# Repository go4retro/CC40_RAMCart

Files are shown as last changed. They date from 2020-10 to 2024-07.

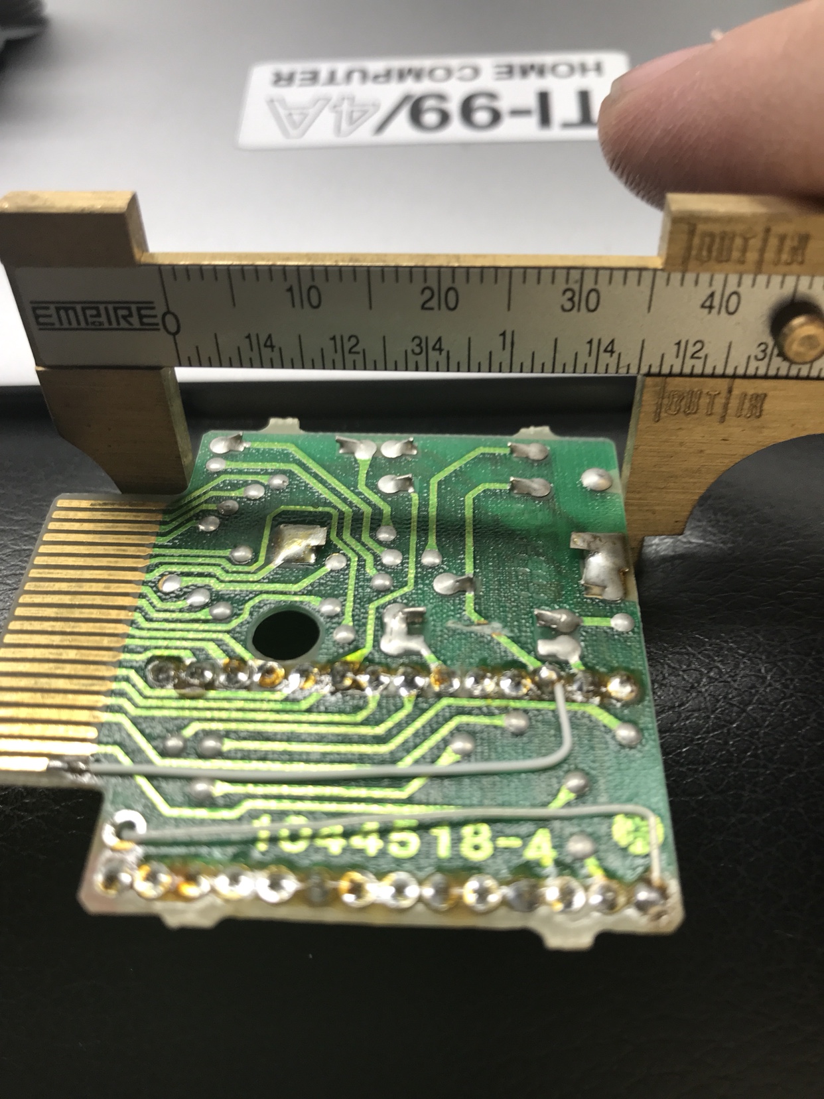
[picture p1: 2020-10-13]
ref/c301821a8f4df3ecedaf89124f83f544.jpg

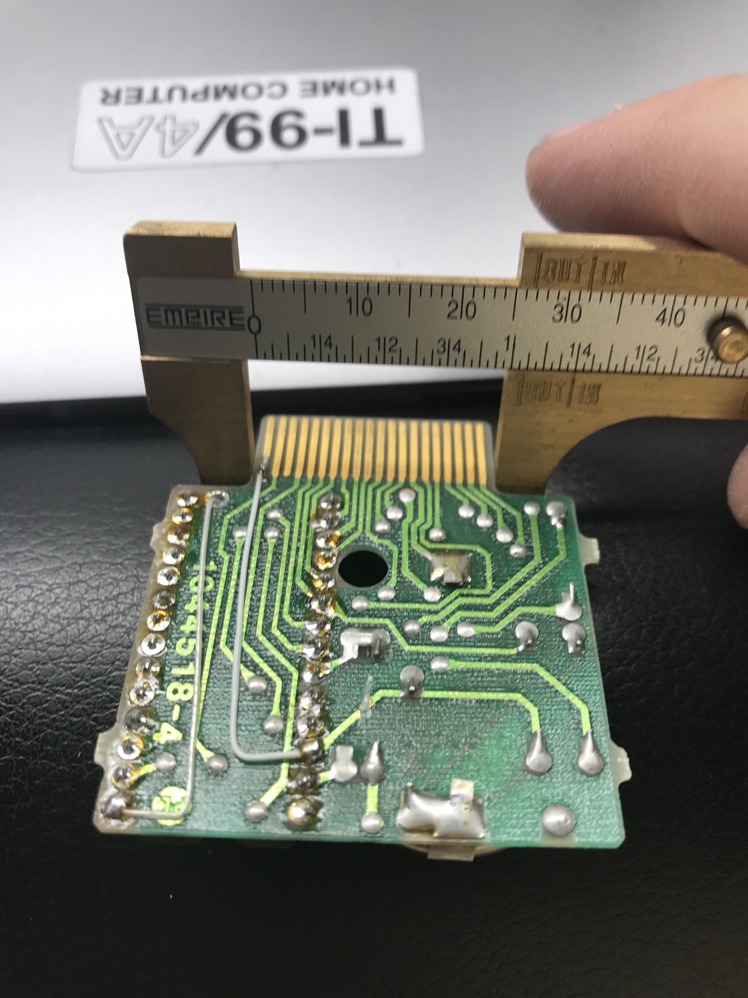
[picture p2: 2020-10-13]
ref/0288a4b47281a45af204f250dd83d3cb.jpg

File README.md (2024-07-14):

## Introduction

Join the growing ranks of Texas Instruments Compact Computer 40 owners who now have increased access to RAM storage on their machine. This CC-40 RAM cartridge replicates the functionality of the original 32kB RAM cartridge option and also expands it 4, 8 or 16 times to  128KB, 256KB, or 512KB.  Easy access DIP switches on the rear of the unit allow one to select which 32kB bank is in use, and all banks are preserved with the optional 3V battery.

Discussion around the design can be reviewed on the AtariAge forum [discussion](https://atariage.com/forums/topic/255728-the-compact-computer-40-cc40/). 

### Main features

- Mimics original PCB location and size
- 4, 8, or 16X capacity
- Easy access to change accessed bank

### Technical Features

- Low power SRAM IC sips battery power when off
- Optional use of P25.2 and P25.3 signals on cartridge port to select RAM bank

## Purchase

This PCB can be purchased in the [RETRO Innovations Online Store](http://store.go4retro.com/ti-compact-computer-40-prototype-boards/).

## License

Copyright (C) 2018  RETRO Innovations

These files are free designs; you can redistribute them and/or modify
them under the terms of the Creative Commons Attribution-ShareAlike 
4.0 International License.

You should have received a copy of the license along with this
work. If not, see <http://creativecommons.org/licenses/by-sa/4.0/>.

These files are distributed in the hope that they will be useful,
but WITHOUT ANY WARRANTY; without even the implied warranty of
MERCHANTABILITY or FITNESS FOR A PARTICULAR PURPOSE.  See the
license for more details.

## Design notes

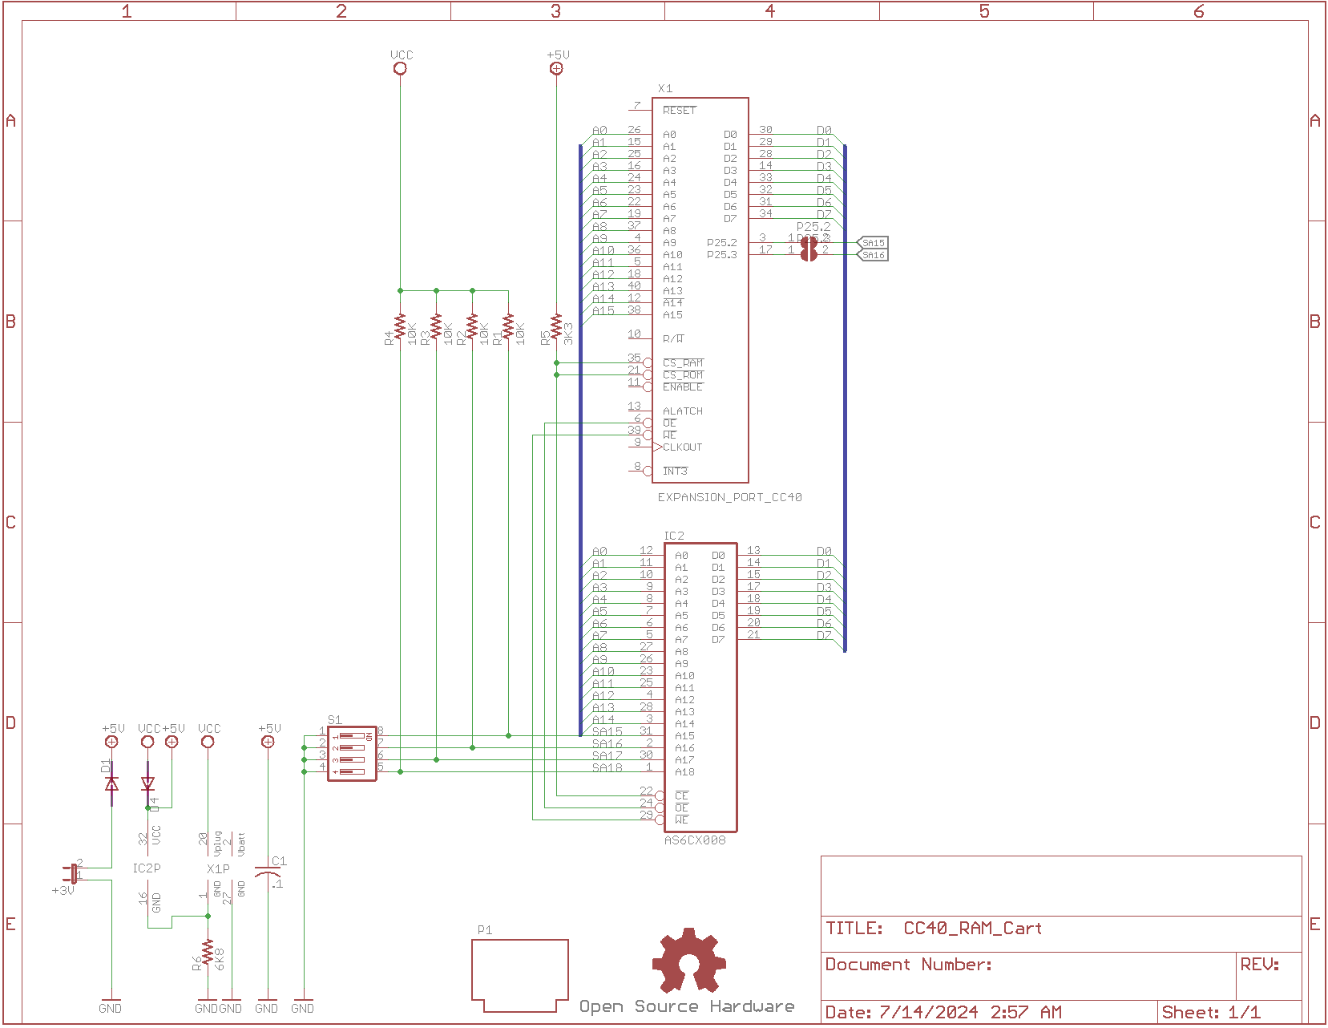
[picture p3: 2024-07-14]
pcb/cc40 RAM Cart Schematic.png

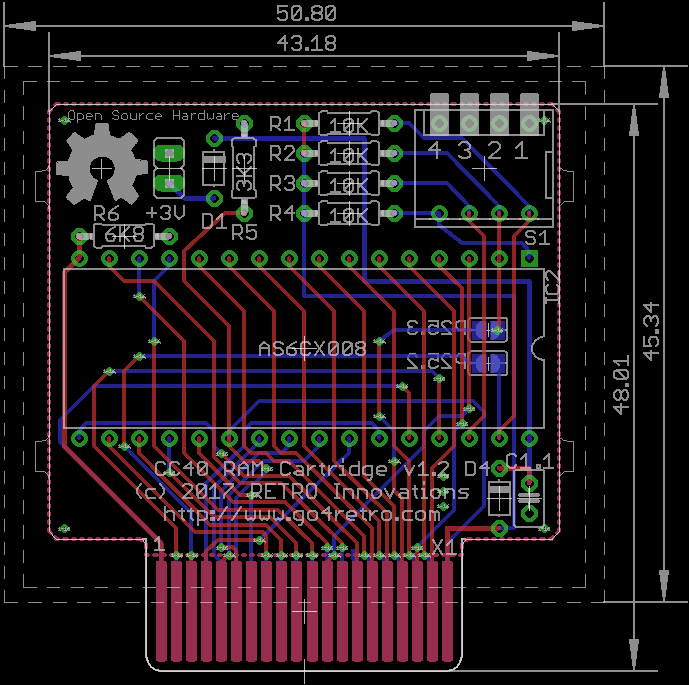
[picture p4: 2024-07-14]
pcb/cc40 RAM Cart PCB.png

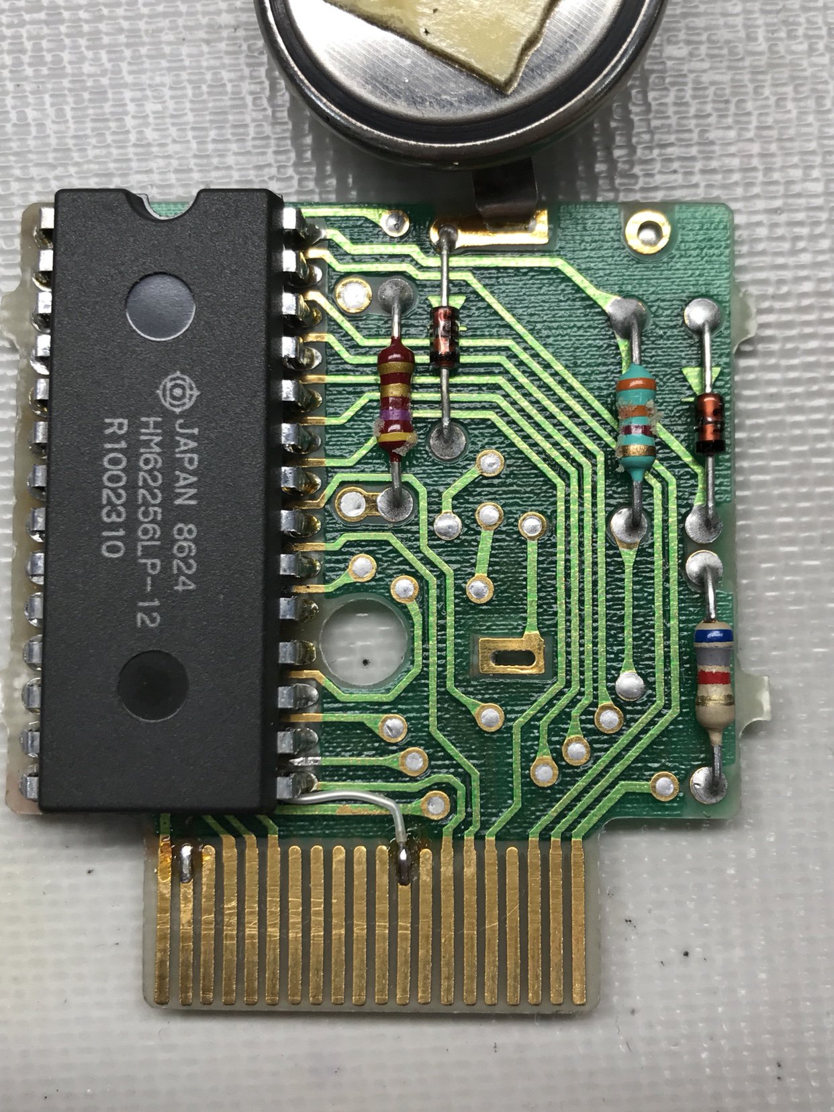
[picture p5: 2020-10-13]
ref/cc97631ac01cea29e733dd045546ecee.jpg

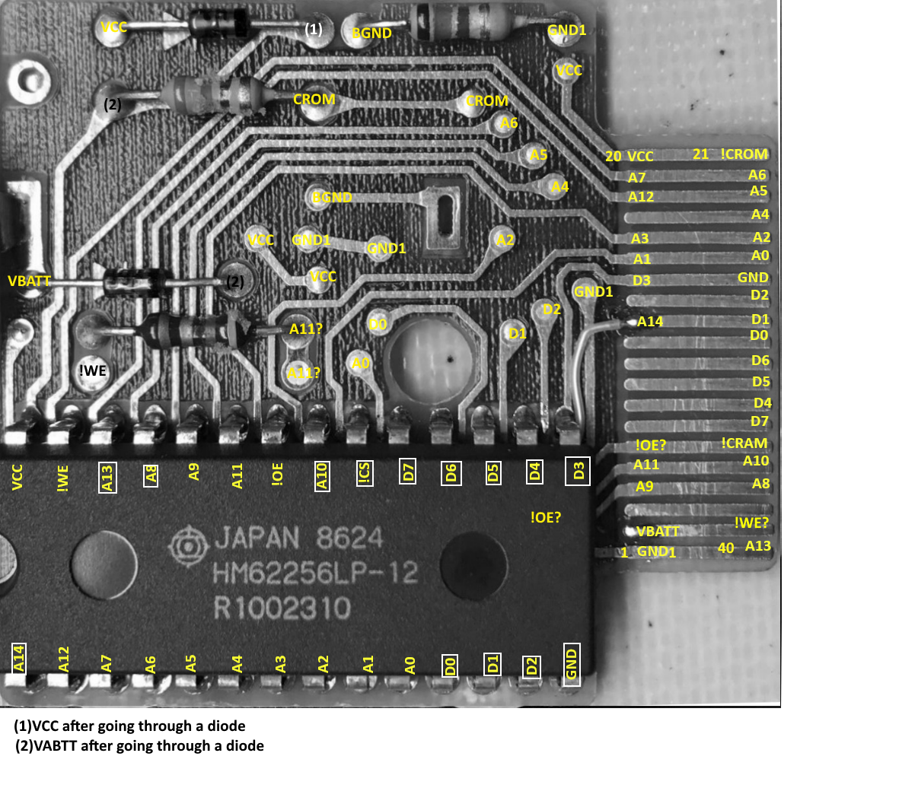
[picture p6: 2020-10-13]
ref/32kB RAM.png

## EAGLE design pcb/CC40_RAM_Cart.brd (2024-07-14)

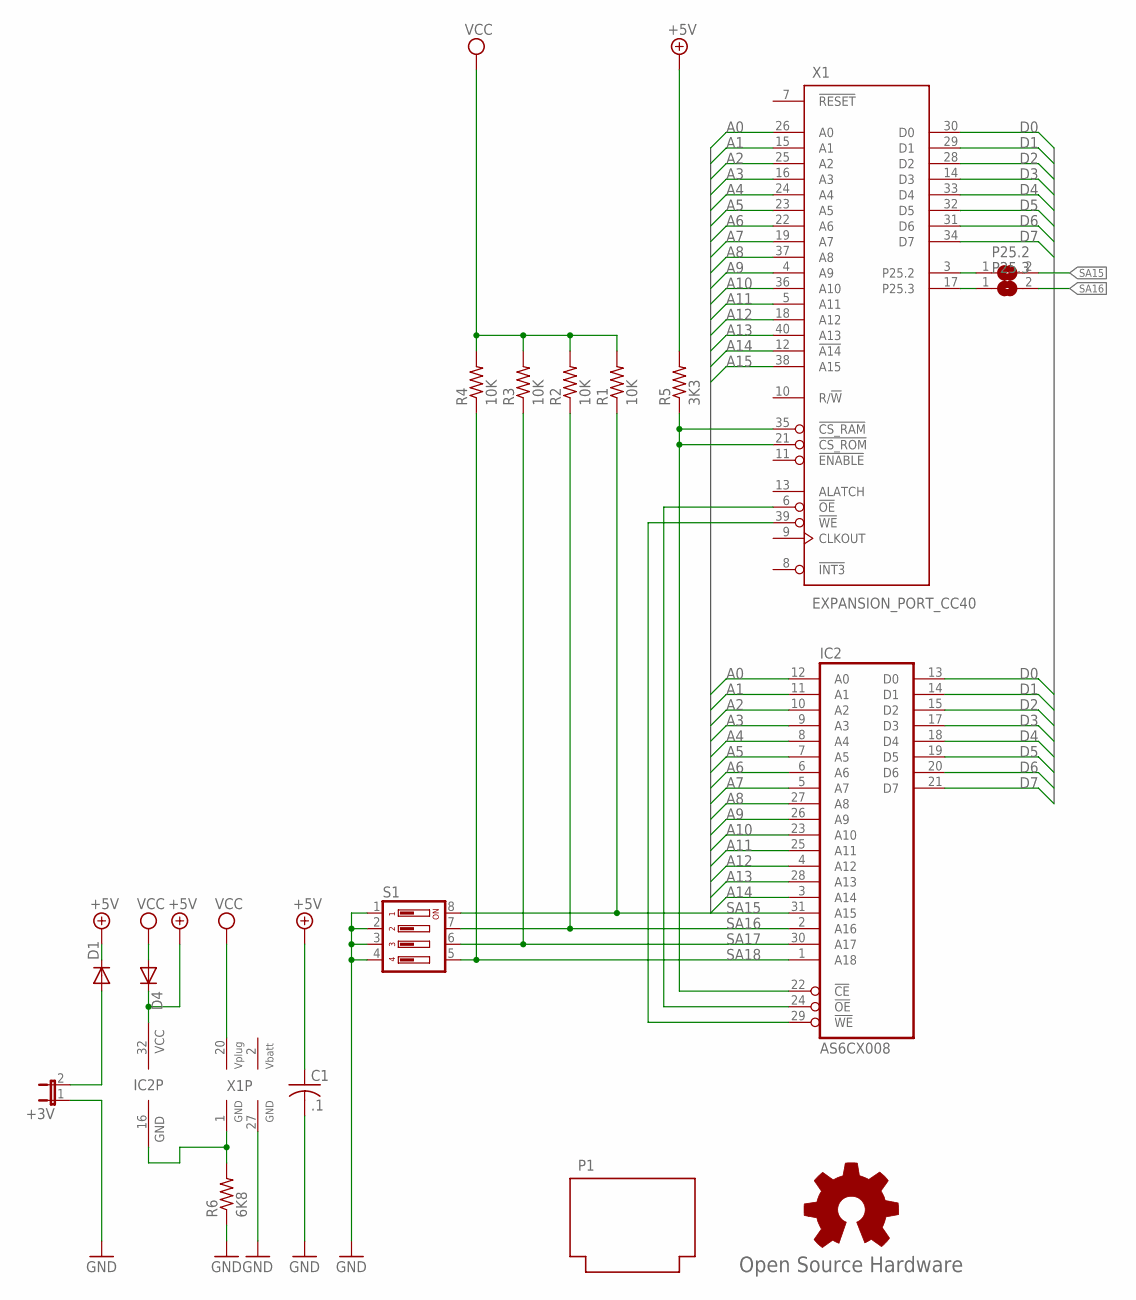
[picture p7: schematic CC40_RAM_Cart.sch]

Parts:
+3V: JP1E; JP1
C1: .1; C025-025X050
D1, D4: DIODE-D-5; D-5
GOLD_ORB_SM1: Open Source Hardware; OSHW_8MM
IC2: AS6CX008; DIL32-RP
P1: CC40_CARTN; CC40_CART_NOHOLE
P25.2, P25.3: SJ
R1, R2, R3, R4: 10K; 0204/7
R5: 3K3; 0204/7
R6: 6K8; 0204/7
S1: DP04; DP-04
X1: EXPANSION_PORT_CC40; MA20-2(.050)

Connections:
!OE: IC2.24 (!OE), X1.6 (!OE)
!WE: IC2.29 (!WE), X1.39 (!WE)
+5V: C1.1, D1.C, D4.C, IC2.32 (VCC), R5.2
A0: IC2.12 (A0), X1.26 (A0)
A1: IC2.11 (A1), X1.15 (A1)
A2: IC2.10 (A2), X1.25 (A2)
A3: IC2.9 (A3), X1.16 (A3)
A4: IC2.8 (A4), X1.24 (A4)
A5: IC2.7 (A5), X1.23 (A5)
A6: IC2.6 (A6), X1.22 (A6)
A7: IC2.5 (A7), X1.19 (A7)
A8: IC2.27 (A8), X1.37 (A8)
A9: IC2.26 (A9), X1.4 (A9)
A10: IC2.23 (A10), X1.36 (A10)
A11: IC2.25 (A11), X1.5 (A11)
A12: IC2.4 (A12), X1.18 (A12)
A13: IC2.28 (A13), X1.40 (A13)
A14: IC2.3 (A14), X1.12 (!A14)
A15: X1.38 (A15)
D0: IC2.13 (D0), X1.30 (D0)
D1: IC2.14 (D1), X1.29 (D1)
D2: IC2.15 (D2), X1.28 (D2)
D3: IC2.17 (D3), X1.14 (D3)
D4: IC2.18 (D4), X1.33 (D4)
D5: IC2.19 (D5), X1.32 (D5)
D6: IC2.20 (D6), X1.31 (D6)
D7: IC2.21 (D7), X1.34 (D7)
GND: +3V.1, C1.2, R6.1, S1.1, S1.2, S1.3, S1.4, X1.27 (GND)
unnamed: IC2.22 (!CE), R5.1, X1.21 (!CS_ROM), X1.35 (!CS_RAM)
unnamed: +3V.2, D1.A
unnamed: IC2.16 (GND), R6.2, X1.1 (GND)
P25.2: P25.2.1, X1.3 (P25.2)
P25.3: P25.3.1, X1.17 (P25.3)
SA15: IC2.31 (A15), P25.2.2, R1.1, S1.8
SA16: IC2.2 (A16), P25.3.2, R2.1, S1.7
SA17: IC2.30 (A17), R3.1, S1.6
SA18: IC2.1 (A18), R4.1, S1.5
VBATT: X1.2 (VBATT)
VCC: D4.A, R1.2, R2.2, R3.2, R4.2, X1.20 (VPLUG)

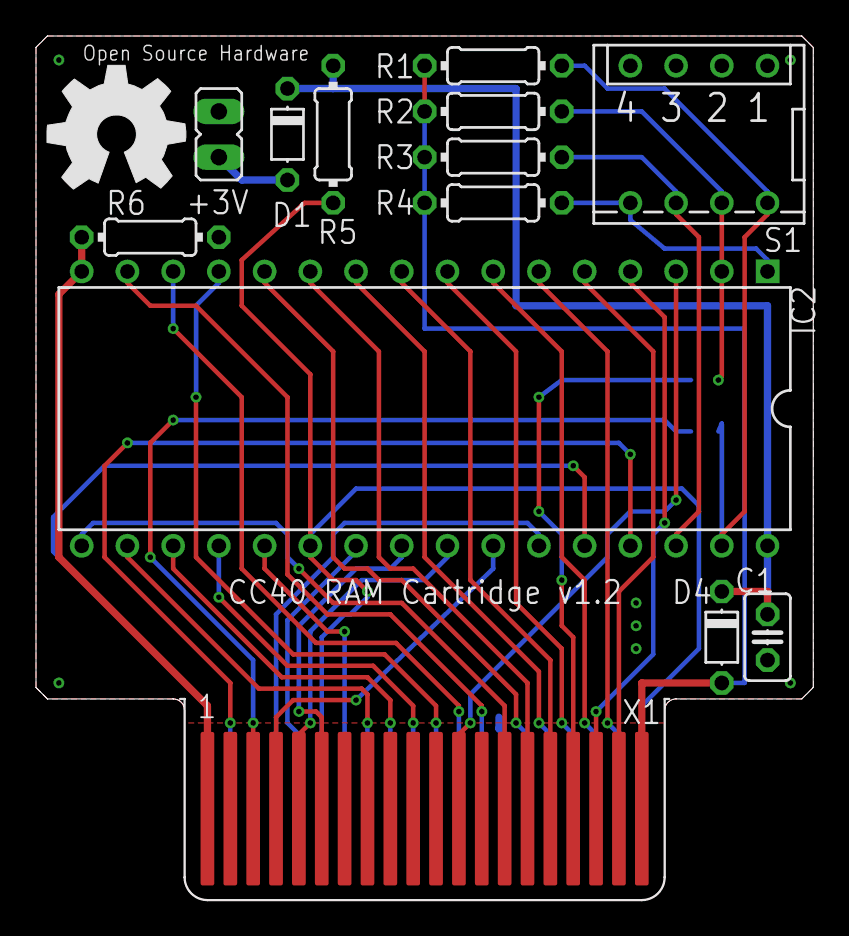
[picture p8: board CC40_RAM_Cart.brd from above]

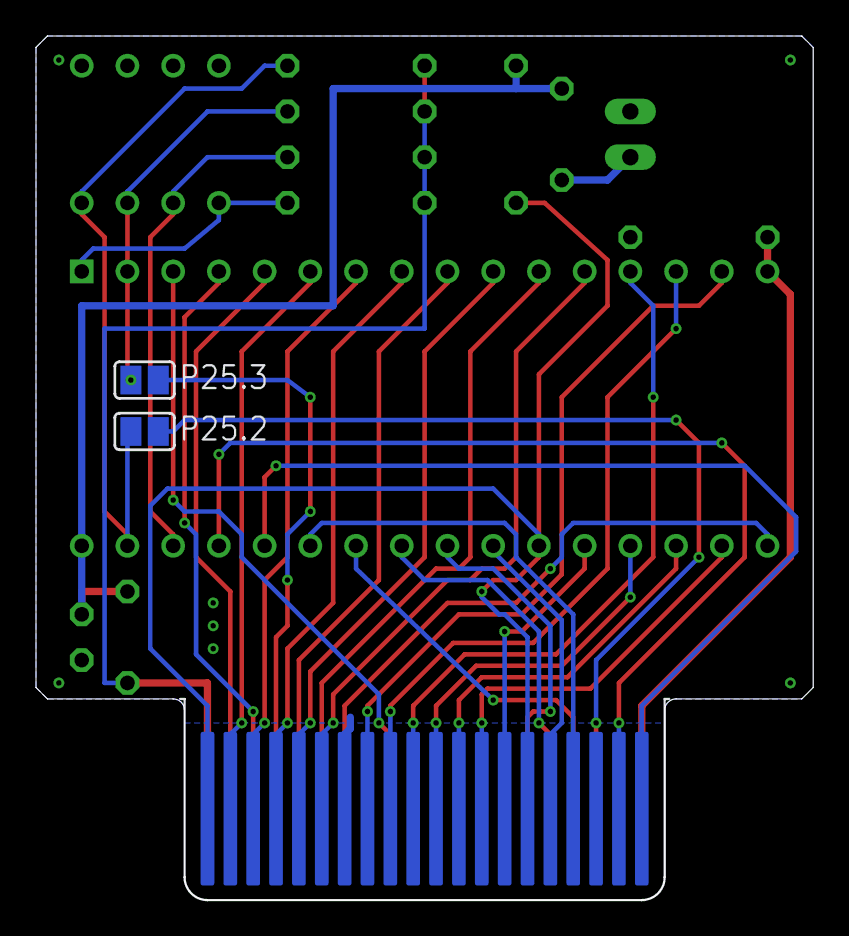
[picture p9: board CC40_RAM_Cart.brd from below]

Board: 2 copper layers, 43.2 x 48.0 mm, 17 parts (2 on the bottom side), 37 nets.

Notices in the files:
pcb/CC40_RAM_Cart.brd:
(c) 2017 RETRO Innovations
